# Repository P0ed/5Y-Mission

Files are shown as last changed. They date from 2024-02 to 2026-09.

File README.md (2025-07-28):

# 5Y-Mission
4U modular analog synthesizer

bw00
bw01
bw10
c11

The panel contains 4 submodules with identical UI. Each unit has:  
* 8 banana jacks and 4 potentiometers laid out in a 4x3 grid  
* 2 5mm LED  
* 2 toggle switches  

### Parts:  
Potentiometer: Bourns 51AAD-B24-A20L  
Banana jack: Pomona 1581  
Switch: NKK A12HP  
Opamp: AD823  
Electronic switch: ADG419/DG419  
Multiplier: AD633  
Zener reference: ADR5045/LM4040  
Flip-flop: CD4013  
NAND: CD4093  
XOR: CD4070  
Counter: CD4029  
VCA: THAT2180  

Resistors SMT: Panasonic 0.1-1% 1206 E6  
Capacitors SMT: TDK C0G 50V 1206 E6  
Resistors THT: Vishay MBA0204 1% 0.4W E6  
Capacitors THT: TDK C0G 50V P:5mm E6  

Board connectors:  
Power: MTA156  
Signal male: 1-826629-6 female:  1-215297-6  

Case connectors:  
Power: AG4MCC  
Audio: AG3MCC  
Controls: AG5MCC  

LEMO connectors:  
FGG.0B.303.CLAD42  
EGG.0B.303.CLL  
PHG.0B.303.CLLD42  

### OSHWLab:
* [PCB panel](https://oshwlab.com/com.poed/panel-typ-i)
* [Dual modules motherboard PCB](https://oshwlab.com/com.poed/motherboard)
* [Mixer module](https://oshwlab.com/com.poed/4u-mixer)
* [Blank module PCB](https://oshwlab.com/com.poed/blank)

### Modules:
* [Voltage mixer](Modules/Mixer.md)
* [4 step sequencer](Modules/Sequencer.md)
* [Function generator](Modules/Function.md)
* AD633 multiplier

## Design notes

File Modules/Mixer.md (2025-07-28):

# Mixer

### Schematic:


[Spice simulation](Mixer.asc)

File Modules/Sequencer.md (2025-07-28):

# Sequencer

The sequencer is based on CD4029 binary counter and ADG429 2:1 multiplexer. It outputs one of the pot values and either of two lowest bits. Acting as a 1:4, 1:2 frequency divider and 4 step CV sequencer. There are two operations: increment the counter or set to IN2 << 1 | IN3.

### Schematic:


[Spice simulation](Sequencer.asc)

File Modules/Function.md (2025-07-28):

# Function generator

Based on first order state variable filter topology. There is a mixer at input, NPN PNP pairs which works as a variable resistor with exponential response and an integrator. Besides SVF there are two flip-flops for attack and decay.

### Schematic:


[Spice simulation](Function.asc)

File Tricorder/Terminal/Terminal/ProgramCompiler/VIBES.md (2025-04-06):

We are designing a simple programming language with compiler and VM.

Compiler is written in Swift and VM is in C for targeting embedded ARM
microcontrollers like Arduino C33 200MHz CPU with 512KB SRAM and 16MB Flash.

The goal is to compile text on a laptop/smartphone (macOS/iOS) into bytecode,
then send the instructions via BLE/WiFi to the microcontroller and execute them there.
The hardware setup and workflow will be similar to Monome Crow,
except for a compiler running on an external device.
Performance wise I'd like to beat Lua while implementing minimum optimisations to keep things simple.
This project only touches the program compilation and execution,
leaving aside any means of communication between devices.

The language is C/Swift inspired with static typing system.
Only static allocation out of the box, with a special case for closures.

Closures are preallocated behind the stack and limited in quantity and size.
There are 256 total closures (255 user-allocatable + 1 reserved).

Exceeding closures count is a runtime error. Exceeding closure size is a compile-time error.
Closure size is 64 words. Word size is 32-bit.

Pointers are 16-bit and minimum offset is a word. Stack size is 256 * 256 * 4 bytes `256KB`.
Closures take up an additional 64 * 256 * 4 bytes `64KB`. Leaving the rest `192KB` to the C runtime.
Pointers can only reference stack. It is not possible to make a pointer to the closures space. 

Instructions are 32-bits wide, with the following layout:
	`opcode: UInt8, x: UInt8, y: UInt8, z: UInt8`.
Some instructions combine `y` and `z` to `yz: UInt16`

Two bits from either `x`, `y` or `z` encode the selector and the remaining 6 bits represent
the register address.

Selectors:
* 0b00 —> top of the stack
* 0b01 —> current closure
* 0b10 —> auxilary closure
* 0b11 —> bottom of the stack

That way it is possible to reference any word in current and aux closures,
and 64 first and last words from the stack in any instruction.
For complete picture, see `machine.h`.

Closures are reference-counted and have reference semantics. The rest has value semantics.

A function can capture a single closure. The same closure may be shared between multiple functions.
When function is called, it's closure, becomes current. Function is static when `closure == 0`.

Function layout:
	`address: UInt16, closure: UInt8, reserved: UInt8`

Capture list is implicit. If any non-root scope variable gets referenced inside a function then it's captured.
Root scope variables are not going anywhere, so it is safe to reference their stack address.

If a function is escaping, then the context it captures resides in a closure instead of a stack. 
Compiler needs to detect escaping. Consider return of the function, passing it as an argument to
another function or storing it to a variable — any of above will mark the function as escaping.

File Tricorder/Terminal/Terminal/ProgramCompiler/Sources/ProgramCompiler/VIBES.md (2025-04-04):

We are designing a simple programming language with compiler and VM.

Compiler is written in Swift and VM is in C for targeting embedded ARM
microcontrollers like Arduino C33 200MHz CPU with 512KB SRAM and 16MB Flash.

My goal is to compile text on a laptop/smartphone (macOS/iOS) to bytecode,
then send instructions via BLE/WiFi to the microcontroller and execute it there.

Performance wise I'd like to beat Lua,
while implementing minimum optimisations to keep everything simple.

The language is C/Swift inspired with static typing system.
Only static allocation out of the box, with a special case for closures.

Closures are preallocated behind the stack and limited in quantity and size
(255 clusures available to user for dynamic allocation + one preallocated reserved closure).

Exceeding closures count is a runtime error. Exceeding closure size is a compile error.
Closure size is 64 words. Word size is 32bit.

Pointers are 16bit and minimum offset is a word. Stack size is 256 * 256 * 4 bytes
(256KB is a half of available SRAM). Closures take additional 64 * 256 * 4 bytes (64KB) 

Instructions are 32bits with layout as follows:
`opcode: UInt8, x: UInt8, y: UInt8, z: UInt8`.

Some instructions combine `y` and `z` to `yz: UInt16`

Two bits from either x, y or z encode selector and remaining 6 bits are the register address.
* Selector 0b00 — points to top of the stack
* Selector 0b01 — points to current closure
* Selector 0b10 — points to auxilary closure
* Selector 0b11 — points to bottom of the stack

That way it is possible to reference any word in current and aux closures,
and 64 first and last words from the stack in any instruction.

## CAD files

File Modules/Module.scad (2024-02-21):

$fn = 48;
in = 25.4;

include <../Parts/1900/1900.scad>

module Banana() {
	scl = 0.97;
	rs = in / 48;
	r = in / 4;
	h = 6.35;
	rt = r * scl - rs;
	hr = in / 8;
	
	difference() {
		union() {
			translate([0, 0, h - rs - rt])
			rotate_extrude()
			translate([rt, rt])
			circle(rs);
			
			linear_extrude(h - rs, scale = scl)
			circle(r);

			linear_extrude(h)
			circle(rt);
		}
		
		translate([0, 0, 2])
		linear_extrude(h)
		circle(hr);
	}
}

module LED() {
	translate([0, 0, 2])
	intersection() {
		linear_extrude(3)
		circle(d = 5);
		
		translate([0, 0, -0.4])
		sphere(d = 5 + 0.1);
	}
	linear_extrude(2.01)
	circle(d = 5);
}

module Button() {
	linear_extrude(2.5)
	circle(d = 5);
}

color("#664400")
translate([in / 2, in / 2])
for(x = [0:3]) for(y = [2:2])
translate([x * in, y * in])
Banana();

color("#222222")
translate([in / 2, in / 2])
for(x = [0:3]) for(y = [1:1])
translate([x * in, y * in])
Banana();

color("#222222")
translate([in / 2, in / 2])
for(x = [0:3]) for(y = [0:0])
translate([x * in, y * in])
Knob(simplify = true);

color("#222222")
translate([in, in])
for(x = [0:1]) for(y = [0:0])
translate([x * in * 2, y * in])
Button();

color("#449955")
translate([in, in])
for(x = [0:1]) for(y = [1:1])
translate([x * in * 2, y * in])
LED();

color("#EEEECC")
translate([0, 0, -2])
linear_extrude(2)
square([in * 4, in * 3]);

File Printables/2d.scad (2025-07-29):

s2 = sqrt(2);
in = 25.4;

module oval(s, ds) {
	function e(x) = 1 - exp(14 * l(x) + 0.33) * 0.000002;
	function l(x) = x / 15;
	function p(x) = [s.x / 2 - ds.x + ds.x * l(x), s.y / 2 - ds.y + e(x) * ds.y];
	function q(pn, q) = q == 0 ? p(pn) :
		q == 1 ? [-p(pn).x, p(pn).y] : 
		q == 2 ? -p(pn) :
		q == 3 ? [p(pn).x, -p(pn).y] : p;
	
	pts = [
		q(15, 1), q(14.7, 1), q(14.3, 1), q(13.8, 1), q(13, 1), q(12, 1), q(11, 1), q(10, 1), q(9, 1), q(8, 1),
		q(7, 1), q(6, 1), q(5, 1), q(4, 1), q(3, 1), q(2, 1), q(1, 1), q(0, 1),
	
		q(0, 0), q(1, 0), q(2, 0), q(3, 0), q(4, 0), q(5, 0), q(6, 0), q(7, 0),
		q(8, 0), q(9, 0), q(10, 0), q(11, 0), q(12, 0), q(13, 0), q(13.8, 0), q(14.3, 0), q(14.7, 0), q(15, 0),
	
		q(15, 3), q(14.7, 3), q(14.3, 3), q(13.8, 3), q(13, 3), q(12, 3), q(11, 3), q(10, 3), q(9, 3), q(8, 3),
		q(7, 3), q(6, 3), q(5, 3), q(4, 3), q(3, 3), q(2, 3), q(1, 3), q(0, 3),
	
		q(0, 2), q(1, 2), q(2, 2), q(3, 2), q(4, 2), q(5, 2), q(6, 2), q(7, 2),
		q(8, 2), q(9, 2), q(10, 2), q(11, 2), q(12, 2), q(13, 2), q(13.8, 2), q(14.3, 2), q(14.7, 2), q(15, 2),
	];
	echo(pts);
	
	polygon(pts);
}

module XLR() {
	d = 24.0;
	id = 23.6;
	hd = 19.0;

	circle(d = id, $fn=32);
	translate([-hd / 2, d / 2]) circle(d=3.2, $fn=16);
	translate([hd / 2, -d / 2]) circle(d=3.2, $fn=16);
}

module LED5() {
	circle(d=5.1, $fn=24);
}

module M3() {
	circle(d = 3.2, $fn=24);
}

module miniXLR() {
	d = 11.2;

	intersection() {
		circle(d = d, $fn=32);
		translate([0, 0.5])
		square([d, d], center=true);
	}
}

module hul(offset) {
	hull() {
		children();
		translate(offset) children();
	}
}

module oct(s, r = 1) {
	translate(-s / 2 + [r, r])
	hul([s.x - r * 2 , 0])
	hul([0, s.y - r * 2])
	circle(r, $fn=4);
}

module oct3(s, r = 1) {
	translate(-s / 2 + [r, r, r])
	hul([s.x - r * 2, 0, 0])
	hul([0, s.y - r * 2, 0])
	hul([0, 0, s.z - r * 2])
	sphere(r, $fn=6);
}

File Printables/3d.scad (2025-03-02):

include <2d.scad>

module hex_mount(m, e, t, r) {
	difference() {
		union() {
			children();
			
			translate(t)
			rotate(r)
			translate(-[0,0, 3.5 + m / 2])
			linear_extrude(m + 6.5)
			rotate([0,0,45])
			circle(d=e + 7 + 3.3, $fn=4);
		}
		
		translate(t)
		rotate(r)
		hul([0, e])
		translate(-[0,0,m/2])
		linear_extrude(m)
		rotate([0,0,90])
		circle(d=e, $fn=6);
		
		translate(t)
		rotate(r)
		translate(-[0,0,(m+7.2)/2])
		linear_extrude(m + 7.2)
		circle(d=3.2, $fn=16);
	}
}

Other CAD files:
Printables/Case UL.scad
Printables/Case.scad
Printables/Knob.scad
Printables/Module.scad
Printables/Panel.scad
Printables/Spacers.scad
Printables/Tricoder AL.scad
Printables/Tricoder.scad
Printables/polyround.scad

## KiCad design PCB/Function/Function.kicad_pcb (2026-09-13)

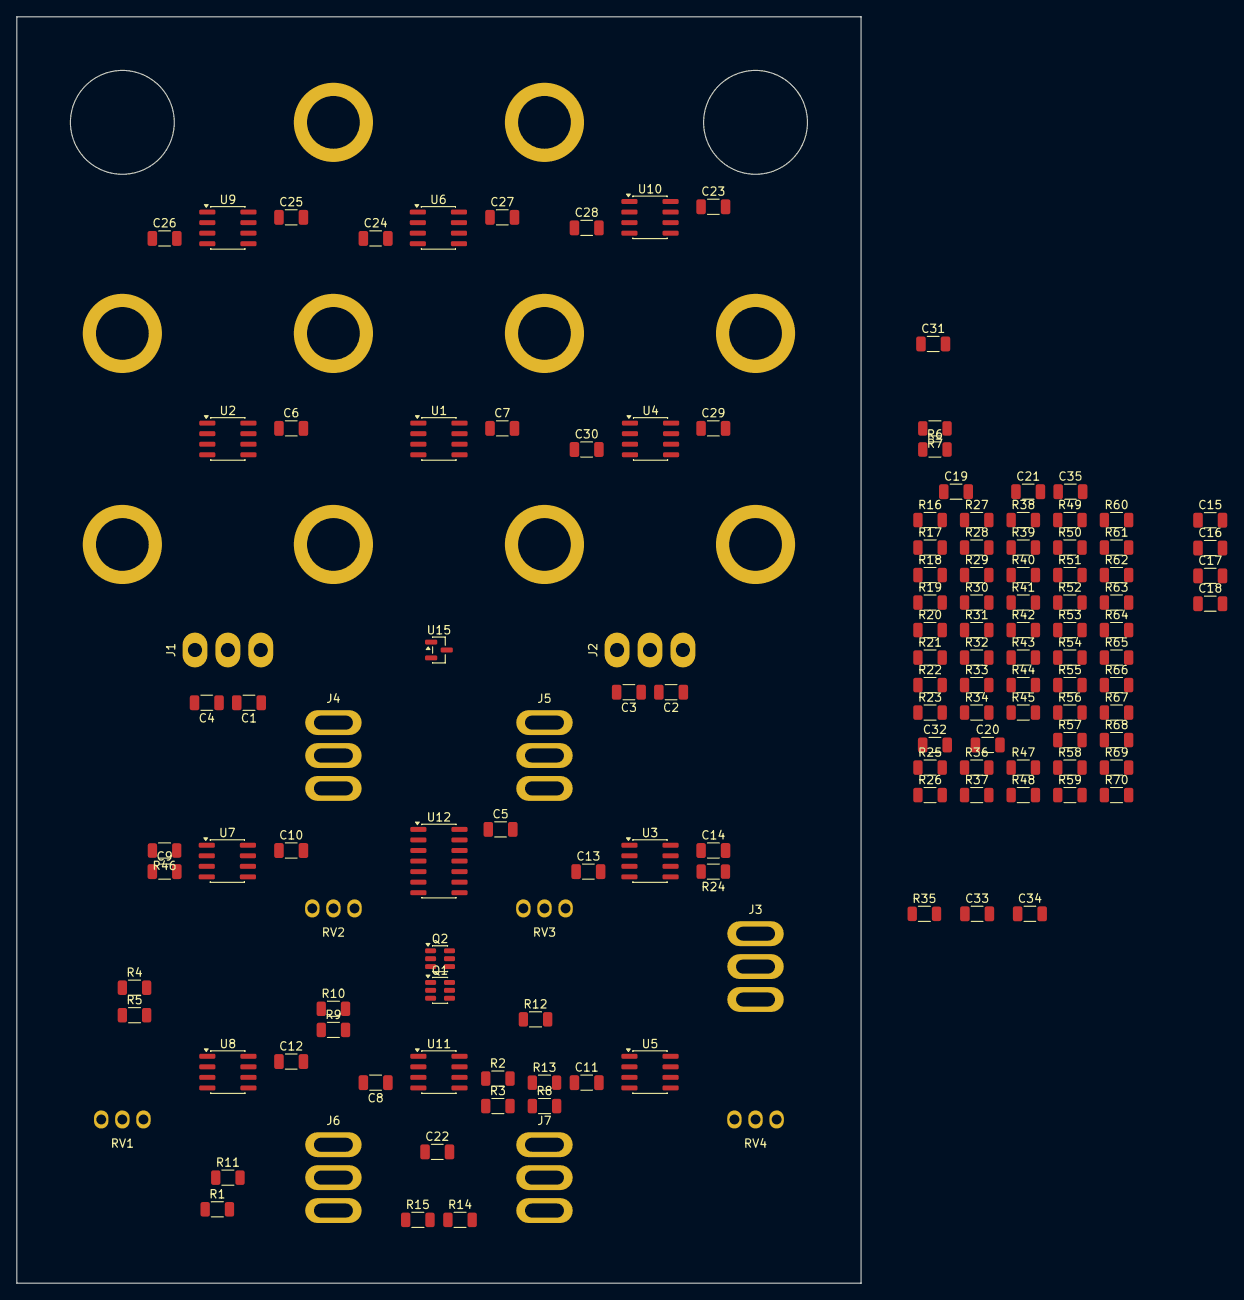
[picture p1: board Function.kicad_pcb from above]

Board: 2 copper layers, 101.6 x 152.4 mm, 141 parts (0 on the bottom side), 75 nets, no tracks yet.

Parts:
C1, C2, C3, C4: 4u7; C_1206_3216Metric
C5, C6, C7, C8, C9, C10, C11, C12, C13, C14, C15, C16, C17, C23, C24, C25, C26, C27, C28, C29, C30: 100n; C_1206_3216Metric
C18, C19, C20, C21, C31, C32, C33, C34, C35: 47p; C_1206_3216Metric
C22: 4n7; C_1206_3216Metric
J1: MTA156-3
J2: MTA156-3-PWR; MTA156-3
J3, J4, J5: MN12; MBNF15
J6, J7: MBNF15
J**1, J**2, J**3, J**4, J**5, J**6, J**7, J**8, J**9, J**10: Pomona_1581; Pomona-1581
Q1: BC847; SOT-23-6
Q2: BCM857; SOT-23-6
R1, R12, R14, R15, R16, R47, R49: 4K7; R_1206_3216Metric
R2, R8, R56: 680K; R_1206_3216Metric
R3, R5, R45, R55: 10K; R_1206_3216Metric
R4, R6, R7, R9, R11, R22, R25, R50, R51, R52, R53, R54, R57, R58, R60, R63, R66, R69: 100K; R_1206_3216Metric
R10, R42, R44, R46, R48, R59, R61, R62, R64, R65, R67, R68, R70: 68K; R_1206_3216Metric
R13, R17, R39, R40: 150K; R_1206_3216Metric
R18: 6M8; R_1206_3216Metric
R19, R21, R24, R27, R29, R30, R31, R32, R34, R35, R36, R37: 47K; R_1206_3216Metric
R20, R28, R33, R38: 470; R_1206_3216Metric
R23, R26, R41, R43: 33K; R_1206_3216Metric
RV1, RV2, RV3, RV4: Bourns_51
U1, U2, U3, U4, U5, U6, U7, U8, U9, U10: AD823; SOIC-8
U11: ADG419; SOIC-8_3.9x4.9mm_P1.27mm
U12: 4013; SOIC-14_3.9x8.7mm_P1.27mm
U15: ADR5045; SOT-23

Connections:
ATK: R9.2, R51.2, U12.1 (Q)
DEK: R52.2, U12.13 (Q)
DRV: C31.2, R44.1, R50.1, U8.1
END: J3.1, R11.1, R22.1, U2.1
ENDO: J**2.1, R19.2, R20.1
FAB: J4.2, U10.6 (-), U10.7
FALLN: J4.1, R66.2
FALLP: J4.3, R69.2
FALL_IN: J**8.1, RV3.3
FAP: R14.1, U10.5 (+)
FB: R70.2, U10.1, U10.2 (-)
FP: RV1.2, U10.3 (+)
FREQ: J**7.1, R62.2, R68.2
GND: C1.2, C2.2, C3.1, C4.1, C5.2, C6.2, C7.2, C8.2, C9.1, C10.2, C11.1, C12.2, C13.1, C14.2, C15.1, C16.2, C17.1, C23.2, C24.1, C25.2, C26.1, C27.2, C28.1, C29.2, C30.1, J1.2, J2.2, Q1.2 (B), Q1.6 (C), Q2.2 (B), Q2.6 (C), R1.1, R4.1, R6.2, R8.1, R10.2, R17.1, R23.1, R26.1, R31.1, R34.1, R36.1, R39.1, R40.1, R42.1, R53.2, R54.2, R58.1, RV1.1, RV2.1, RV3.1, RV4.1, U1.4 (V-), U2.4 (V-), U5.5 (+), U6.3 (+), U6.5 (+), U7.3 (+), U7.5 (+), U11.3 (GND), U12.3 (C), U12.4 (R), U12.6 (S), U12.7 (VSS), U12.8 (S), U12.9 (D), U12.11 (C), U15.2 (A)
HOLD: R56.1, U8.7, U11.6
HOLD_IN: J**10.1, R54.1, R55.2
LIM: R13.1, R25.1, U2.7
LIMO: J**5.1, R27.2, R28.1
LP: C22.2, R12.2, R21.1, R24.1, R29.1, R35.1, R43.2, U1.5 (+), U2.2 (-), U5.7
LPO: J**1.1, R37.2, R38.1
NLPO: J**4.1, R32.2, R33.1
NVFF: C32.2, R46.1, R65.2, U7.1
NVRF: C35.2, Q1.5 (B), R49.1, U6.1
unnamed: C18.2, R20.2, U3.1
unnamed: C19.2, R28.2, U3.7
unnamed: C20.2, R33.2, U4.7
unnamed: C21.2, R38.2, U4.1
unnamed: R1.2, U1.6 (-)
unnamed: Q1.1 (E), Q1.4 (E), Q2.1 (E), Q2.4 (E), R45.1
unnamed: Q1.3 (C), Q2.3 (C), U11.1
unnamed: R14.2, RV3.2
unnamed: R15.2, RV4.2
unnamed: R45.2, U5.1
unnamed: R2.1, R3.2, U1.3 (+)
unnamed: R6.1, R7.2, U1.2 (-)
unnamed: R9.1, R10.1, R11.2, R18.2, U2.3 (+)
unnamed: R16.1, R17.2, U2.5 (+)
unnamed: R12.1, R13.2, U2.6 (-)
unnamed: R22.2, R23.2, R40.2, U3.3 (+)
unnamed: C18.1, R19.1, R21.2, U3.2 (-)
unnamed: R25.2, R26.2, R39.2, U3.5 (+)
unnamed: C19.1, R24.2, R27.1, U3.6 (-)
unnamed: R35.2, R36.2, U4.3 (+)
unnamed: C21.1, R34.2, R37.1, U4.2 (-)
unnamed: R30.2, R31.2, U4.5 (+)
unnamed: C20.1, R29.2, R32.1, U4.6 (-)
unnamed: R43.1, R44.2, U5.3 (+)
unnamed: R41.1, R42.2, U5.2 (-)
unnamed: C22.1, U5.6 (-), U11.2
unnamed: C35.1, R49.2, R59.1, R60.1, R61.1, U6.2 (-)
unnamed: C34.1, R48.2, R62.1, R63.1, R64.1, U6.6 (-)
unnamed: C32.1, R46.2, R66.1, R67.1, U7.2 (-)
unnamed: C33.1, R47.2, R65.1, R68.1, R69.1, R70.1, U7.6 (-)
unnamed: R52.1, R53.1, U8.3 (+)
unnamed: C31.1, R50.2, R51.1, U8.2 (-)
unnamed: R55.1, R56.2, U8.5 (+)
unnamed: R57.1, R58.2, U8.6 (-)
RAB: J5.2, U9.1, U9.2 (-)
RAP: R15.1, U9.3 (+)
RB: R64.2, U9.6 (-), U9.7
REF: J6.1, J7.1, R5.1, R7.1, R16.2, R18.1, R30.1, R57.2, R61.2, R67.2, RV1.3, RV2.3, U15.1 (K)
RISEN: J5.1, R60.2
RISEP: J5.3, R63.2
RISE_IN: J**9.1, RV4.3
RP: RV2.2, U9.5 (+)
SIGB: J6.2, R41.2
SIG_IN: J6.3, J**3.1
TRIG: R2.2, U1.1
TRIGB: J7.2, R3.1, R4.2
TRIGSW: J3.2, R8.2, U12.5 (D)
TRIG_IN: J7.3, J**6.1
VCC: C1.1, C2.1, C5.1, C6.1, C7.1, C8.1, C10.1, C12.1, C14.1, C16.1, C23.1, C25.1, C27.1, C29.1, J1.3, J2.3, J3.3, R5.2, U1.8 (V+), U2.8 (V+), U3.8 (V+), U4.8 (V+), U5.8 (V+), U6.8 (V+), U7.8 (V+), U8.8 (V+), U9.8 (V+), U10.8 (V+), U11.4 (V+), U11.5 (VL), U12.10 (R), U12.14 (VDD)
VEE: C3.2, C4.2, C9.2, C11.2, C13.2, C15.2, C17.2, C24.2, C26.2, C28.2, C30.2, J1.1, J2.1, U3.4 (V-), U4.4 (V-), U5.4 (V-), U6.4 (V-), U7.4 (V-), U8.4 (V-), U9.4 (V-), U10.4 (V-), U11.7 (V-)
VFF: C33.2, Q2.5 (B), R47.1, U7.7
VRF: C34.2, R48.1, R59.2, U6.7

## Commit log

2023-10-25 Add panel and parts datasheets
    [Panel.dxf, Panel.scad, Panel.stl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]
2024-02-20 Add 1900 knob clone
    [1900.scad, threads.scad]
2024-02-21 Update module
    [1900.scad, Module.scad]
2024-03-24 Update simulations and parts list
    [1900.scad, Case.scad, Jack spacer.stl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]
2024-03-30 Update function
    [Knob.scad]
2024-05-20 Add motherboard
    [Spacers.scad]
2024-06-29 Update case and spacers
    [Case.scad, Panel.scad, Spacers.scad]
2024-09-05 Update function design
    [Case UL.scad, Knob.scad, Spacers.scad]
2024-10-17 Add tricoder
    [2d.scad, Case UL.scad, Case.scad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]
2025-03-02 Add tricorder
    [2d.scad, 3d.scad, Tricoder AL.scad]
2025-04-07 Update module 3d model
    [Knob.scad, Module.scad]
2025-07-29 Add NPN-Slope
    [2d.scad, Panel.scad]
2026-02-26 Add Fn.asc
    [Function.kicad_pcb, Function.kicad_sch]
2026-03-01 Add flip-flop, END, LIM
    [Function.kicad_sch]
2026-03-02 Update simulation
    [Function.kicad_pcb, Function.kicad_sch]
2026-03-04 Update Function schematic
    [Function.kicad_sch]
2026-03-04 Start placement
    [Function.kicad_pcb, Function.kicad_sch]
2026-03-04 Compactify schematics
    [Function.kicad_pcb, Function.kicad_sch]
2026-09-13 Update fn
    [Function.kicad_pcb, Function.kicad_sch]
